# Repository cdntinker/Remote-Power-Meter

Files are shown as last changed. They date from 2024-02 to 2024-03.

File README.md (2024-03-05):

## The Jacks
* J1 Power / Communications
* J2 Source connection for USB
* J3 Source connection for whatever
* J4 Source connection for whatever
* J5 Load connection for USB
* J6 Load connection for whatever
* J7 Load connection for whatever
* Disp1 Little OLED screen

## JP1 & JP2
These allow 4 of the possible 16 addresses for the INA219 chip.

The chip allows for 16 addresses by tying A0 & A1 to GND, VS+, SCL & SDA is various conbinations but I don't feel that much chaos is warranted in this case.

## R1 & R2
These are the shunt resistor that the INA219 uses for measuring current. There are 2 resistors in parallel to improve power handling (& possibly accuracy). 

A 2816 SMD resistor can typically handle ~2W and the initial design incentive is a device capable of supplying 4W.

## The LEDs
D1 is for indicating connection status.

D2 is intended to show alerts & such at a glance.

JP3 is just there to allow for driving the LEDs from either raw 5v (from the USB supply) or 3v3 (from the regulator).

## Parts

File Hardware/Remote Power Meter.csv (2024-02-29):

Component Count: | 40
Ref | Qnty | Cmp name | Value | LCSC | DigiKey | Footprint | Description
C1, | 1 | CP | 22uf | C145122 |  | Capacitor_Tantalum_SMD:CP_EIA-6032-28_Kemet-C_Pad2.25x2.35mm_HandSolder
C2, C3, C5, C6, C7, | 5 | C | 0.1 | C14663 |  | Capacitor_SMD:C_0603_1608Metric_Pad1.08x0.95mm_HandSolder | Unpolarized capacitor
C4, | 1 | C | 10nf | C161232 |  | Capacitor_SMD:C_0603_1608Metric_Pad1.08x0.95mm_HandSolder | Unpolarized capacitor
D1, D2, | 2 | WS2812B | WS2812B | C2843785 |  | LED_SMD:LED_WS2812B_PLCC4_5.0x5.0mm_P3.2mm | RGB LED with integrated controller
Disp1, | 1 | Conn_01x04_Female | Cheap Ali OLED |  |  | Connector_PinSocket_2.54mm:PinSocket_1x04_P2.54mm_Vertical | Generic connector, single row, 01x04, script generated (kicad-library-utils/schlib/autogen/connector/)
J1, | 1 | USB_C_Receptacle_USB2.0 | USB_C_Receptacle_USB2.0 | C2765186 |  | Tinker:USB_C_Receptacle_HRO_TYPE-C-31-M-12 | USB 2.0-only Type-C Receptacle connector
J2, | 1 | 48037-0001 | 48037-0001 | C136455 |  | Tinker:USB-A-TH_48037-0001
J3, J7, | 2 | Conn_01x04_Male | Conn_01x04_Male |  |  | Connector_PinHeader_2.54mm:PinHeader_1x04_P2.54mm_Vertical | Generic connector, single row, 01x04, script generated (kicad-library-utils/schlib/autogen/connector/)
J4, J6, | 2 | Conn_01x02 | Conn_01x02 | C784940 |  | TerminalBlock_4Ucon:TerminalBlock_4Ucon_1x02_P3.50mm_Horizontal | Generic connector, single row, 01x02, script generated (kicad-library-utils/schlib/autogen/connector/)
J5, | 1 | USB_A | USB_A | C6389922 |  | Connector_USB:USB_A_CONNFLY_DS1095-WNR0 | USB Type A connector
Q1, | 1 | UMH3N | UMH3N | C62892 |  | Package_TO_SOT_SMD:SOT-363_SC-70-6 | 0.1A Ic, 50V Vce, Dual NPN Input Resistor Transistors, SOT-363
R1, R2, | 2 | R | 0.1 | C844084 |  | Resistor_SMD:R_2816_7142Metric_Pad3.20x4.45mm_HandSolder | Resistor
R3, R4, | 2 | R | 10 | C22859 |  | Resistor_SMD:R_0603_1608Metric_Pad0.98x0.95mm_HandSolder | Resistor
R5, R6, R9, R10, R11, R12, R13, R14, R16, R17, | 10 | R | 10K | C25804 |  | Resistor_SMD:R_0603_1608Metric_Pad0.98x0.95mm_HandSolder | Resistor
R7, R8, | 2 | R | 5k1 | C23203 |  | Tinker:R_0603_1608Metric_Pad0.98x0.95mm_HandSolder | Resistor
R15, | 1 | R | 470 | C114669 |  | Resistor_SMD:R_0603_1608Metric_Pad0.98x0.95mm_HandSolder | Resistor
SW1, | 1 | SW_Push | SW_Push | C2858276 |  | Tinker:SW_Push_TS273014TP | Push button switch, generic, two pins
U1, | 1 | AMS1117-3.3 | AMS1117-3.3 | C347256 |  | Package_TO_SOT_SMD:SOT-223-3_TabPin2 | 1A Low Dropout regulator, positive, 3.3V fixed output, SOT-223
U2, | 1 | INA219AxD | INA219 | C138706 |  | Package_SO:SOIC-8_3.9x4.9mm_P1.27mm | Zero-Drift, Bidirectional Current/Power Monitor (0-26V) With I2C Interface, SOIC-8
U3, | 1 | CH340G | CH340C | C84681 |  | Package_SO:SOIC-16_3.9x9.9mm_P1.27mm | USB serial converter, UART, SOIC-16
Um1, | 1 | ESP-M3 | ESP-M3 | C19949058 |  | Tinker:ESP-M3

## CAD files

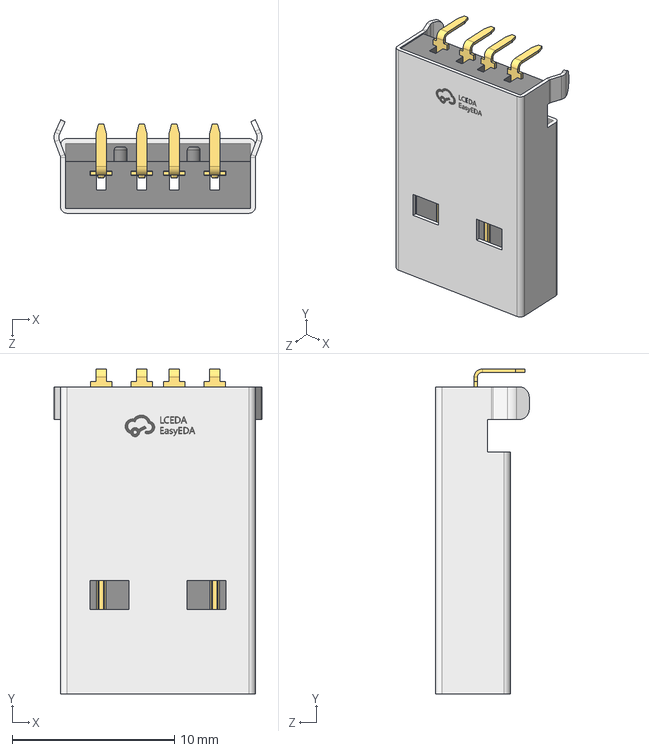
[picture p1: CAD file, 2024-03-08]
Hardware/KiCAD Customs/3D/USB-A-TH_48037-0001.step
12.8 x 20.0 x 5.76 mm

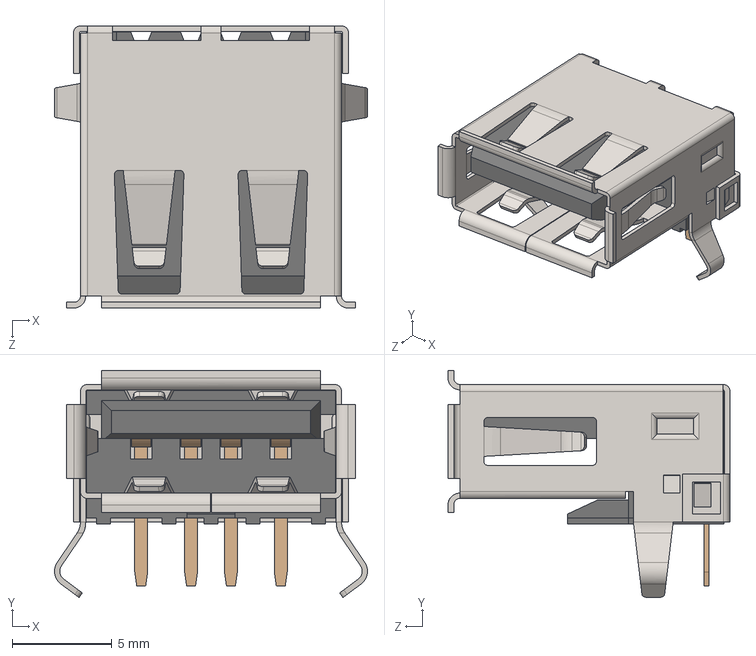
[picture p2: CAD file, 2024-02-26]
Hardware/KiCAD Customs/3D/USB Connector Type A female.STEP
15.7 x 11.4 x 14.1 mm

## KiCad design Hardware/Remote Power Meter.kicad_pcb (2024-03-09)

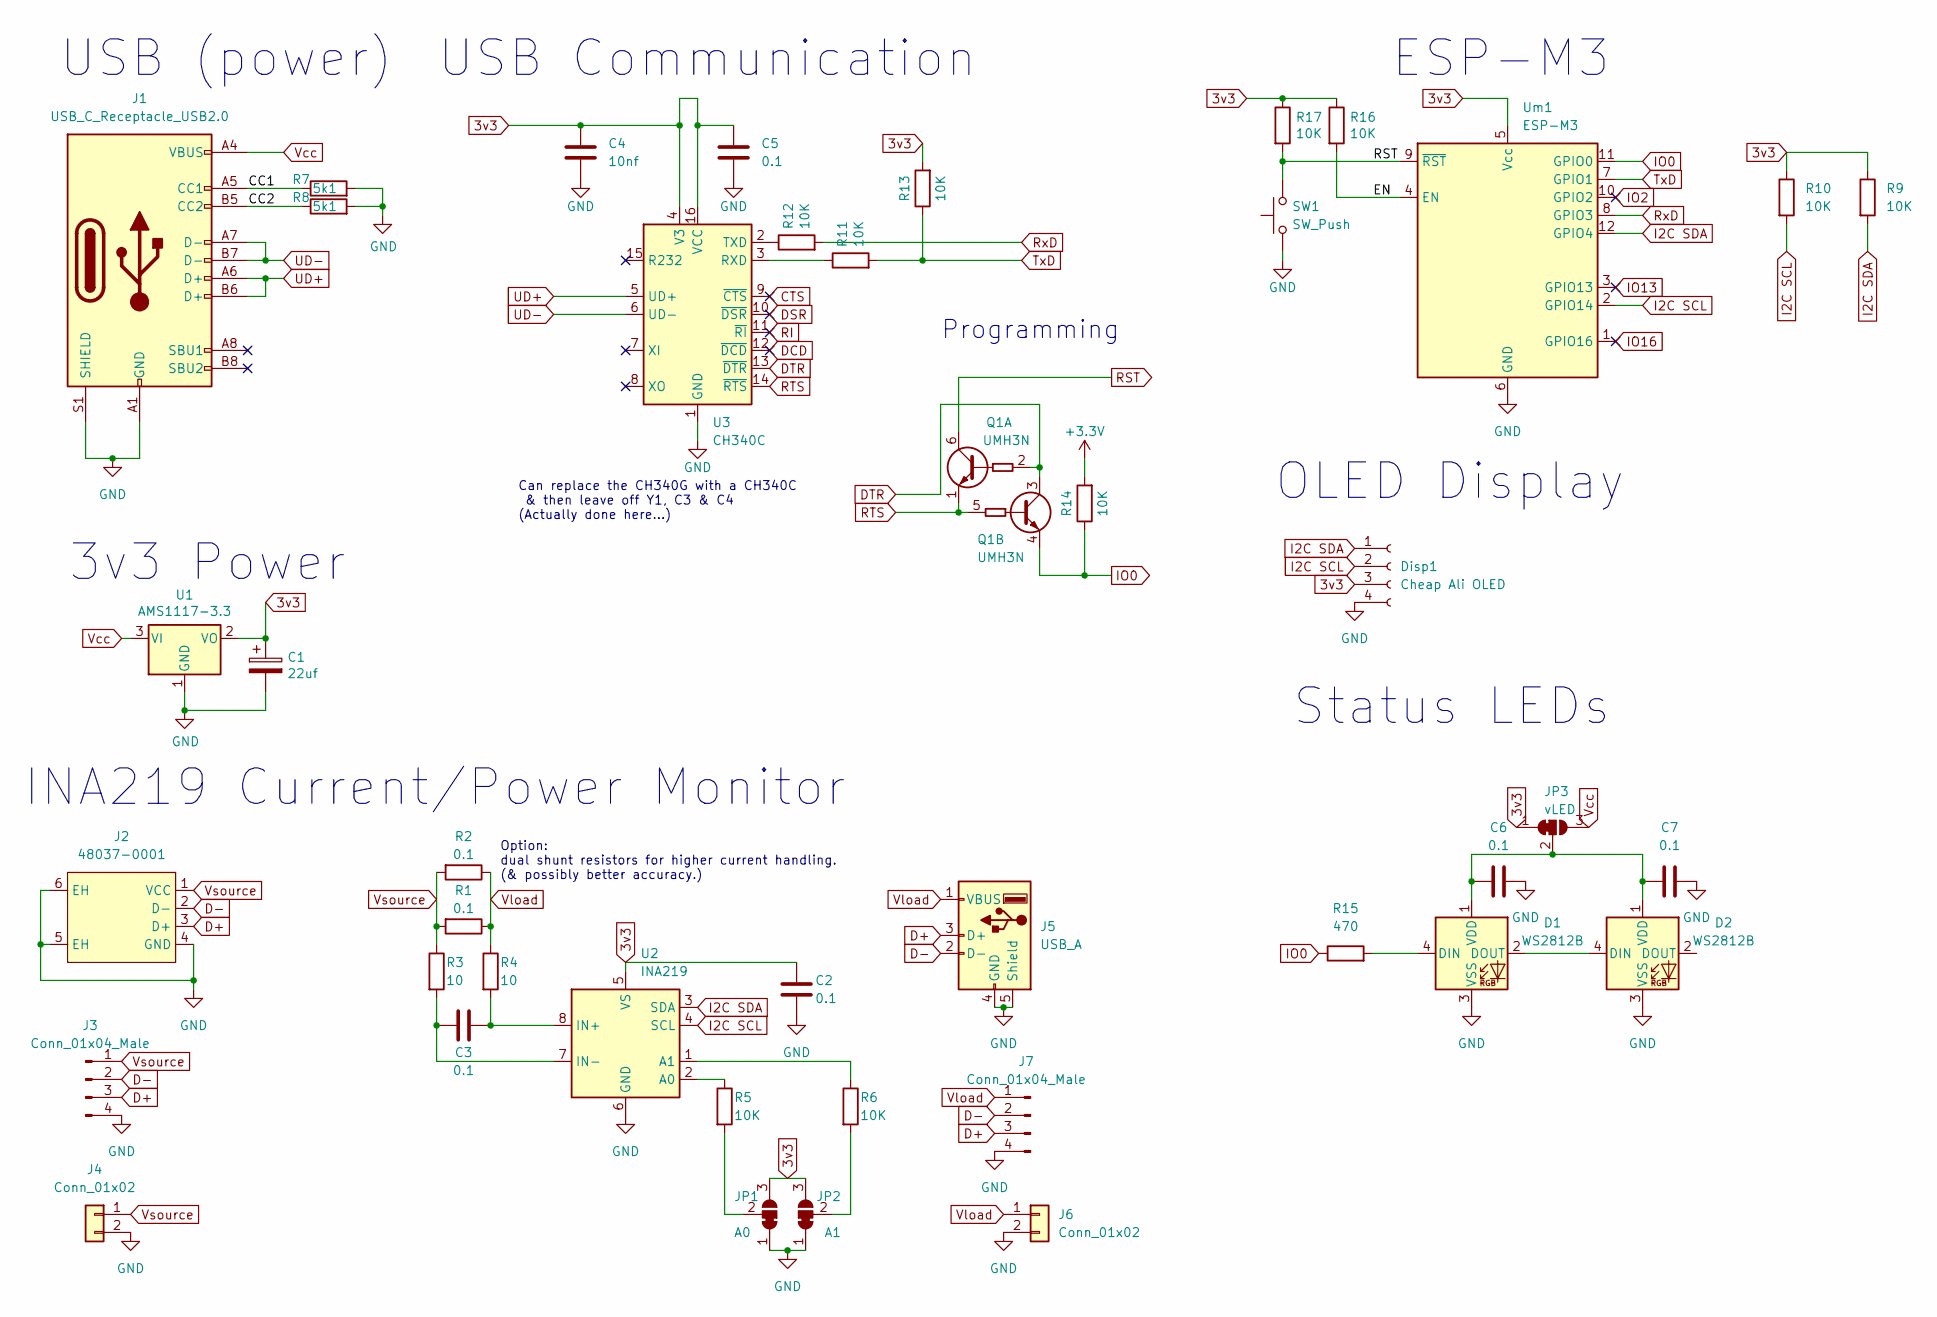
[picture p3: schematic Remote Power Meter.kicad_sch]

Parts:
C1: 22uf; CP_EIA-6032-28_Kemet-C_Pad2.25x2.35mm_HandSolder; LCSC C145122
C2, C3, C5, C6, C7: 0.1; C_0603_1608Metric_Pad1.08x0.95mm_HandSolder; LCSC C14663
C4: 10nf; C_0603_1608Metric_Pad1.08x0.95mm_HandSolder; LCSC C161232
D1, D2: WS2812B; LED_WS2812B_PLCC4_5.0x5.0mm_P3.2mm; LCSC C2843785
Disp1: Cheap Ali OLED; PinSocket_1x04_P2.54mm_Vertical
J1: USB_C_Receptacle_USB2.0; USB_C_Receptacle_HRO_TYPE-C-31-M-12; LCSC C2765186
J2: 48037-0001; USB-A-TH_48037-0001; LCSC C136455
J3, J7: Conn_01x04_Male; PinHeader_1x04_P2.54mm_Vertical
J4, J6: Conn_01x02; TerminalBlock_4Ucon_1x02_P3.50mm_Horizontal; LCSC C784940
J5: USB_A; USB_A_CONNFLY_DS1095-WNR0; LCSC C6389922
JP1: A0; SolderJumper-3_P1.3mm_Bridged12_RoundedPad1.0x1.5mm
JP2: A1; SolderJumper-3_P1.3mm_Bridged12_RoundedPad1.0x1.5mm
JP3: vLED; SolderJumper-3_P1.3mm_Bridged12_RoundedPad1.0x1.5mm
Q1: UMH3N; SOT-363_SC-70-6; LCSC C62892
R1, R2: 0.1; R_2816_7142Metric_Pad3.20x4.45mm_HandSolder; LCSC C844084
R3, R4: 10; R_0603_1608Metric_Pad0.98x0.95mm_HandSolder; LCSC C22859
R5, R6, R9, R10: 10K; R_0603_1608Metric_Pad0.98x0.95mm_HandSolder
R7, R8: 5k1; R_0603_1608Metric_Pad0.98x0.95mm_HandSolder; LCSC C23203
R11, R12, R13, R14, R16, R17: 10K; R_0603_1608Metric_Pad0.98x0.95mm_HandSolder; LCSC C25804
R15: 470; R_0603_1608Metric_Pad0.98x0.95mm_HandSolder; LCSC C114669
SW1: SW_Push; SW_Push_TS273014TP; LCSC C2858276
U1: AMS1117-3.3; SOT-223-3_TabPin2; LCSC C347256
U2: INA219; SOIC-8_3.9x4.9mm_P1.27mm; LCSC C138706
U3: CH340C; SOIC-16_3.9x9.9mm_P1.27mm; LCSC C84681
Um1: ESP-M3; LCSC C19949058

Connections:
3v3: C1.1, C2.1, C4.1, C5.2, Disp1.3, JP1.3 (B), JP2.3 (B), JP3.1 (A), R9.1, R10.1, R13.2, R16.1, R17.1, U1.2 (VO), U2.5 (VS), U3.4 (V3), U3.16 (VCC), Um1.5 (Vcc)
+3V3: R14.2
/CC1: J1.A5 (CC1), R7.1
/CC2: J1.B5 (CC2), R8.1
/EN: R16.2, Um1.4 (EN)
CTS: U3.9 (~CTS)
D+: J2.3 (D+), J3.3, J5.3 (D+), J7.3
D-: J2.2 (D-), J3.2, J5.2 (D-), J7.2
DCD: U3.12 (~DCD)
DSR: U3.10 (~DSR)
DTR: Q1.2 (B1), Q1.3 (C2), U3.13 (~DTR)
GND: C1.2, C2.2, C4.2, C5.1, C6.2, C7.2, D1.3 (VSS), D2.3 (VSS), Disp1.4, J1.A1 (GND), J1.A12 (GND), J1.B1 (GND), J1.B12 (GND), J1.S1 (SHIELD), J2.4 (GND), J2.5 (EH), J2.6 (EH), J3.4, J4.2, J5.4 (GND), J5.5 (Shield), J6.2, J7.4, JP1.1 (A), JP2.1 (A), R7.2, R8.2, SW1.1, U1.1 (GND), U2.6 (GND), U3.1 (GND), Um1.6 (GND)
I2C SCL: Disp1.2, R10.2, U2.4 (SCL), Um1.2 (GPIO14)
I2C SDA: Disp1.1, R9.2, U2.3 (SDA), Um1.12 (GPIO4)
IO0: Q1.4 (E2), R14.1, R15.1, Um1.11 (GPIO0)
IO2: Um1.10 (GPIO2)
IO13: Um1.3 (GPIO13)
IO16: Um1.1 (GPIO16)
unnamed: C3.1, R4.2, U2.8 (IN+)
unnamed: C3.2, R3.2, U2.7 (IN-)
unnamed: C6.1, C7.1, D1.1 (VDD), D2.1 (VDD), JP3.2 (C)
unnamed: D1.2 (DOUT), D2.4 (DIN)
unnamed: D1.4 (DIN), R15.2
unnamed: JP1.2 (C), R5.2
unnamed: JP2.2 (C), R6.2
unnamed: R5.1, U2.2 (A0)
unnamed: R6.1, U2.1 (A1)
unnamed: R11.1, U3.3 (RXD)
unnamed: R12.1, U3.2 (TXD)
RI: U3.11 (~RI)
RST: Q1.6 (C1), R17.2, SW1.2, Um1.9 (~RST)
RTS: Q1.1 (E1), Q1.5 (B2), U3.14 (~RTS)
RxD: R12.2, Um1.8 (GPIO3)
TxD: R11.2, R13.1, Um1.7 (GPIO1)
UD+: J1.A6 (D+), J1.B6 (D+), U3.5 (UD+)
UD-: J1.A7 (D-), J1.B7 (D-), U3.6 (UD-)
Vcc: J1.A4 (VBUS), J1.A9 (VBUS), J1.B4 (VBUS), J1.B9 (VBUS), JP3.3 (B), U1.3 (VI)
Vload: J5.1 (VBUS), J6.1, J7.1, R1.1, R2.1, R4.1
Vsource: J2.1 (VCC), J3.1, J4.1, R1.2, R2.2, R3.1

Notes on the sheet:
OLED Display
Status LEDs
Programming
ESP-M3
USB (power)
3v3 Power
Can replace the CH340G with a CH340C & then leave off Y1, C3 & C4 (Actually done here...)
USB Communication
Option: dual shunt resistors for higher current handling. (& possibly better accuracy.)
INA219 Current/Power Monitor

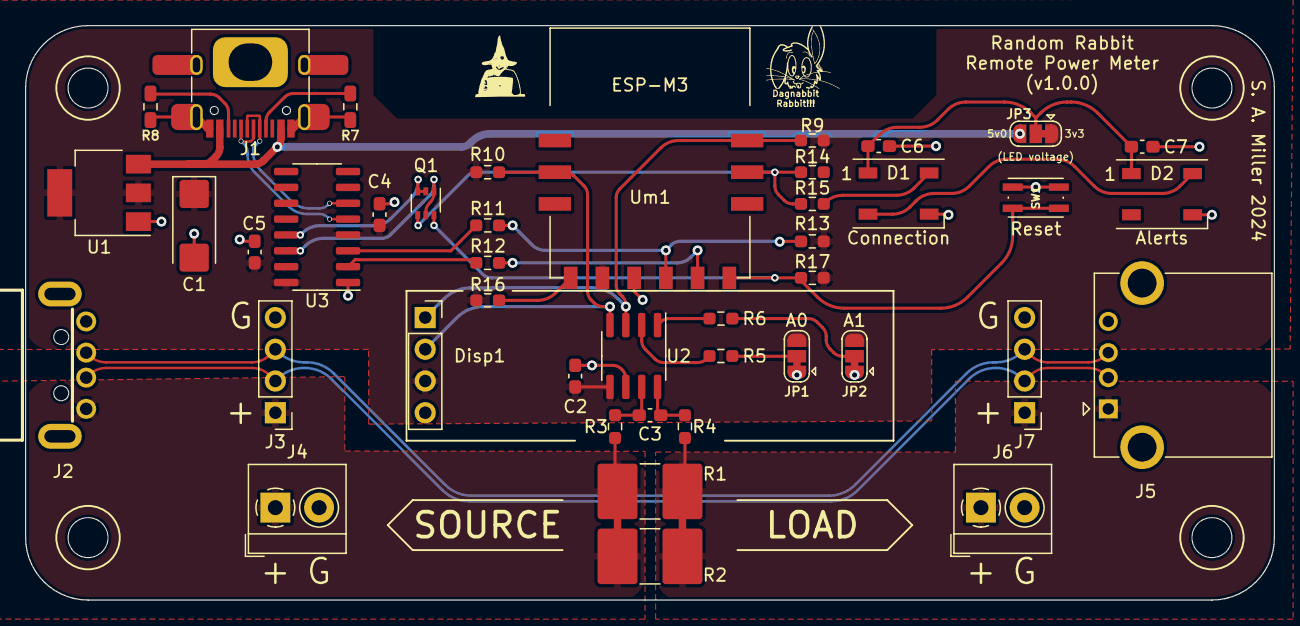
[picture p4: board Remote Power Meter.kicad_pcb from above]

Board: 2 copper layers, 100.0 x 46.0 mm, 43 parts (0 on the bottom side), 31 nets.

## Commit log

2024-02-25 Moved hardware into subfolder
    [Remote Power Meter.kicad_pcb, Remote Power Meter.kicad_sch]
2024-02-26 Now programmable via USB
    [Remote Power Meter.kicad_pcb, Remote Power Meter.kicad_sch]
2024-02-26 Possibly reached v1.0.0
    [Remote Power Meter.kicad_pcb, Remote Power Meter.kicad_sch, USB Connector Type A female.STEP]
2024-02-29 Added LCSC BOM
    [Remote Power Meter.csv, Remote Power Meter.kicad_pcb, Remote Power Meter.kicad_sch]
2024-03-08 bye bye bloody wrl file(s)
    [Remote Power Meter.kicad_pcb, USB-A-TH_48037-0001.step]
2024-03-09 bye bye bloody wrl files
    [Remote Power Meter.kicad_pcb]
